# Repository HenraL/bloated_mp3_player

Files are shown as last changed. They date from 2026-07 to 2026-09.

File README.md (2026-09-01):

<!-- 
-- +==== BEGIN Bloated MP3 Player =================+
-- LOGO:
-- .......................
-- ...><>.............<><.
-- ..><>.><>.......<><.<><
-- .><>.<><.><>.<><.<><.<>
-- ..><>.><>.......<><.<><
-- ...><>.............<><.
-- .......................
-- /STOP
-- PROJECT: Bloated MP3 Player
-- FILE: README.md
-- CREATION DATE: 23-07-2026
-- LAST Modified: 14:19:29 01-09-2026
-- DESCRIPTION:
-- This is the code in charge of making the bloated player come to life.
-- /STOP
-- COPYRIGHT: (c) Henry Letellier
-- PURPOSE: This is the file that presents and explains the projects aim.
-- // AR
-- +==== END Bloated MP3 Player =================+
-->
# **DON'T PANIC**

## bloated_mp3_player

> **The answer is 42. The question, it turns out, is: "How many peripherals can you bolt onto an ESP32 before the scheduler files for divorce?"**

This is a multithreaded embedded project that started life as a humble MP3 player and, through a series of unfortunate events vaguely resembling a real-time systems course, accreted so many non-essential components that it now requires a concurrent scheduler just to keep them all arguing fairly for CPU time.

It runs on an ESP32-S3 (the electronic equivalent of an Infinite Improbability Drive, only slightly less likely to turn you into a potted plant or a philosophical whale), uses FreeRTOS under the hood (courtesy of the Arduino framework), and demonstrates that you can, in fact, teach concurrency by strapping seventeen unrelated sensors to a single I²C bus and hoping for the best.

## Contents

> *"Please read the signs before panic."*

- [About](#about) — why a Vogon would raise an eyebrow
- [Disclaimer](#disclaimer) — we tried to warn you
- [Dependencies](#dependencies) — the unhealthy soil it all grows in
- [Components Used](#components-used) — the BOM of doomed hardware
- [Divorce proceedings](#divorce-proceedings) — a strained peripheral marriage
- [How to Flash](#how-to-flash) — the very real thermonuclear toolchain
- [How to Use](#how-to-use) — but there is no off switch
- [Bonus Tools](#bonus-tools) — flamegraphs & baked fonts
- [License](#license) — so long, and thanks for all the fish

## About

> *"The ships hung in the sky in much the same way that bricks don't."*
> — Douglas Adams, *The Hitchhiker's Guide to the Galaxy*

This program is a multithreaded C++ monstrosity for the Real Time Embedded Systems course at **Unimore Enzo Ferrari AI and engineering department**. It was inspired by *The Hitchhiker's Guide to the Galaxy* not because it does anything particularly galactic, but because the sheer quantity of peripherals tacked onto it would make even a Vogon constructor fleet raise an eyebrow.

The core mission: play MP3s from a microSD card while simultaneously monitoring temperature, humidity, air pressure, rotation, acceleration, magnetic fields, and the existential dread of a WS2812B RGB matrix trying to decide what colour to be or where to put the bablefish.

Is it practical? No.
Does it demonstrate concurrency? Absolutely.
Would Zaphod Beeblebrox approve? Almost certainly, right before stealing it.

## Disclaimer

- This program is provided **as is**, without warranty of any kind — implied, express, or Vogon-constructed. If your ESP32 achieves sentience and demands a better quality MP3 files, that's your problem.
- This program was written with the assistance of AI. The AI is not responsible for any design decisions, but it did try to talk us out of the 16×16 RGB matrix. We didn't listen.
- Developed under **Ubuntu 24.04.4 LTS**, where ESP32s tend to materialise on `/dev/ttyACM0` (unless they're feeling contrary, in which case check `dmesg`).
- Targeted at the **ESP32-S3 WROOM FREENOVE** dev board. Flashed via the PlatformIO extension for VS Code (or however one normally communicates with small, irritable computers).
- The [KiCad schematic](./hardware/) is provided as a wiring reference. You could send it to a PCB manufacturer if you're feeling brave, but the author (and his AI accomplice) accept no responsibility for design issues, misplaced vias, or spontaneous combustion.
- Components are universally sourcable from websites such as Amazon, AliExpress, or (for the truly adventurous) by flagging down a passing Dentrassi supply ship.

## Dependencies

The software stack, from bottom to top:

| Layer | What it is | Why it's here |
| --- | --- | --- |
| FreeRTOS | Real-time OS (via Arduino) | So 17 tasks can deadlock each other in style |
| Arduino ESP32 Core | HAL / framework | Because writing raw ESP-IDF is for people with more patience |
| [Adafruit NeoPixel](https://github.com/adafruit/Adafruit_NeoPixel) | RGB LED control | Makes the matrix glow reassuringly |
| [U8g2](https://github.com/olikraus/u8g2) | OLED/LCD monochrome graphics | Draws text and badly-scaled album art on the 128×64 LCD |
| [arduino-libhelix](https://github.com/pschatzmann/arduino-libhelix) | Fixed-point MP3 decoder | Helix-based MP3 decoding with PSRAM support; because software decoding without it is like a Vogon without a thesaurus |

Most library dependencies materialise automagically from the PlatformIO ether. The exception is the one that does the actual heavy lifting — see the submodule note below, and try not to think about what happens if you forget `--recursive`.

### Git Submodule: arduino-libhelix

> *"The major difference between a thing that might go wrong and a thing that cannot possibly go wrong is that when a thing that cannot possibly go wrong goes wrong, it usually turns out to be impossible to get at or repair."*
> — Douglas Adams, *Mostly Harmless*

This library lives at `platformio/bloated_mp3_player/lib/arduino-libhelix` and is not a PlatformIO registry package — it is, officially, A Thing That Cannot Possibly Go Wrong.

To initialise it (and thereby disprove the above quote):

```bash
git clone --recursive <repository-url>
```

If you cloned without `--recursive` (you magnificent fool):

```bash
git submodule update --init --recursive
```

PlatformIO scans `lib/` automatically, so the submodule compiles itself into the firmware with no further configuration. If this sounds too easy, re-read the quote at the top of this section.

## Components Used

> *"The Guide is definitive. Reality is frequently inaccurate."*
> — *The Hitchhiker's Guide to the Galaxy*

The following have been sacrificed on the altar of concurrency:

| Purpose | Name | Price (€) | Quantity | Link |
| --- | --- | --- | --- | --- |
| :brain: The brains | Freenove ESP32-S3-WROOM CAM — Dual-core 32-bit 240 MHz | 20.19 | 1 | [AliExpress](https://aliexpress.com/item/1005004960637276.html) |
| :tv: Display | Lcd12864 12864-06D — COG dot matrix, SPI, with Chinese font | 6.19 | 1 | [AliExpress](https://aliexpress.com/item/1005009024477658.html) |
| :receipt: Cash-register display | TZT LCD2004+I2C — 2004A 20x4 HD44780 char LCD with I2C adapter soldered on the back | 4.85 | 1 | [AliExpress](https://aliexpress.com/item/1005004726086089.html) |
| :scroll: Vogon ticker | LCD1602+I2C Module — 16x2 HD44780 char LCD, PCF8574T IIC interface, 5 V (blue, I2C soldered on the back) | 2.63 | 1 | [AliExpress](https://aliexpress.com/item/1005006170395488.html) |
| :thermometer: Weather station | AHT20+BMP280 — Temperature, humidity & air pressure | 1.20 | 1 | [AliExpress](https://aliexpress.com/item/1005007702473893.html) |
| :triangular_ruler: Distance | HC-SR04 — Ultrasonic "how far is the wall" sensor | 1.41 | 1 | [AliExpress](https://aliexpress.com/item/1005007849944952.html) |
| :arrows_counterclockwise: User input | EC11 Rotary Encoder with switch — 20 positions, knob shaft | 3.49 | 1 | [AliExpress](https://aliexpress.com/item/1005004908084537.html) |
| :loud_sound: Crappy beeps | 4Ω 3W / 8Ω 2W cavity speaker — tiny, tinny, test-tones only | 1.38 | 2 | [AliExpress](https://aliexpress.com/item/1005008626624201.html) |
| :compass: Orientation | GY-9250 MPU-9250 — 9-axis gyro + accel + magnetometer | 3.09 | 1 | [AliExpress](https://aliexpress.com/item/1005007211455522.html) |
| :flashlight: Light show | WS2812B 16×16 RGB LED matrix — individually addressable chaos | 14.39 | 1 | [AliExpress](https://aliexpress.com/item/1005005394534715.html) |
| :floppy_disk: Storage | Micro SD Card Module — SPI level-shifted | 1.24 | 1 | [AliExpress](https://aliexpress.com/item/1005010653353565.html) |

**Total carnage:** ~€62.06 plus fuses, caps, and whatever else you inevitably forgot.

The two character displays (2004A + 1602A) arrive with their I2C adapter boards pre-soldered on the back, so no extra PCF8574 wiring is needed — just VCC/GND/SDA/SCL to the bus. Mind the addresses though: they ship defaulted to 0x27, so the second one needs the A0 pad bridged (0x26) to live on the same bus as the first.

For fuses, capacitors, resistors, and the 5 V → 3.3 V regulators, see the schematic. You probably have them in a drawer somewhere. The author assumes no responsibility for the state of that drawer.

### Divorce proceedings

> *"I am the President of the Galaxy. I'm not in the mood for a diplomatic relationship."*

Despite our best efforts, the development prototype has filed for divorce with two of its peripherals: the STN 128×64 LCD and the WS2812B matrix have gone silent (presumably due to wiring disagreements). The firmware driving both of them is still running, faithfully poking the pins every task tick — so if the wiring ever is reconciled, they may snap back to life like nothing happened. No firmware update required. Just cable therapy.

The I2C character displays, meanwhile, have fully reconciled: the 2004A info panel (folder browser, track names, volume, uptime) and the 1602A Vogon poetry panel (which also breathes IMU orientation readouts between stanzas) are both happily married to the bus. If the big LCD and matrix ever announce a reconciliation, this entry will be updated accordingly.

## How to Flash

> *"A towel is about the most massively useful thing an interstellar hitchhiker can have."*

1. Load some `.mp3` files onto a microSD card. 44.1 kHz, 16-bit stereo is the recommended flavour of the universe.
2. Insert the card into the ESP32's SD card reader (or the module you soldered on after muttering imprecations at the pinout).
3. Open the project in VS Code with the PlatformIO extension installed. If you don't have PlatformIO, you're about to have a Very Bad Time.
4. Connect your ESP32. There are usually two USB ports: one for UART (debug) and one for OTG (flash). **The OTG one is the one you want.** If you get it wrong, nothing explodes — you'll just get a timeout. This is fine.
5. Locate the **`→`** arrow at the bottom of the VS Code window. Click it. This compiles the firmware and, if the stars align, flashes it to the board.
6. If the flash fails: check the port, hold the BOOT button, and try again. Repeat until the universe stops playing tricks on you.

### Pre-flight flash erase

A PlatformIO extra script (`middleware/full_erase.py`) automatically erases the ESP32's flash before each upload. This ensures no stale data haunts your new firmware like the ghost of a Vogon poem.

It can also be run standalone:

```bash
python middleware/full_erase.py                          # auto-detect port
python middleware/full_erase.py --port /dev/ttyUSB0      # explicit port
```

It will find `esptool.py` in your PATH, or tell you to `pip install esptool` if you haven't.

## How to Use

> *"In the beginning, the universe was created. This has made a lot of people very angry and been widely regarded as a bad move."*

Turn the rotary encoder to navigate. Selection is two-stage: rotate to pick a
folder (album), press once to step inside and browse its tracks, rotate to the
track you want, press again to play it. Double- or triple-click the knob to skip
forward/back a track while playing (or to pop back to the album list while
browsing inside a folder). Wave a hand once past the ultrasonic sensor to pause,
and wave it twice quickly to abandon the current track and return to the menu.

The interface appears on the SPI LCD and the 2004A info panel, which shows the
current folder, track, volume and uptime (hh:mm:ss). The 1602A recites Vogon
poetry and periodically trades buffers with the IMU to show roll/pitch/yaw. The
RGB matrix will do something presumably artistic if its wiring ever gets talked
off the ledge. The ultrasonic sensor will judge your distance from the board.
The MPU-9250 will ponder its orientation in the cosmos. The temperature sensor
will inform you that it is, in fact, room temperature.

There is no off switch. You have been warned.

## Bonus Tools

### Flamegraph Profiling (bonus/extras/flamegraph.py)

The firmware includes a lightweight profiler that can dump task timing traces and CPU usage stats over the serial port. The `flamegraph.py` script converts that output into an interactive SVG flamegraph — a visual representation of where the CPU is spending its time (or, as the Guide would put it, "how the microprocessor is frittering away the microseconds").

**To capture profiling data:**

1. In the firmware, ensure `Profiling::dump_traces()` or `Profiling::dump_task_stats()` is called. The output appears on the serial console (typically 115200 baud) in sections bracketed by `=== PROFILING TRACES ===` / `=== END PROFILING TRACES ===`.
2. Save that serial output to a file:

   ```bash
   platformio device monitor --raw > serial_dump.txt
   ```

   Press the reset button to trigger the dump, then hit Ctrl+C to stop.
3. Generate the flamegraph:

   ```bash
   python bonus/extras/flamegraph.py serial_dump.txt
   ```

   This produces `flamegraph.svg` (or `flamegraph_traces.svg` / `flamegraph_task_stats.svg` if multiple sections are present).
4. Open the SVG in any browser. The wider a bar, the more time that function consumed. Hover for details.

**Usage summary:**

```bash
python bonus/extras/flamegraph.py < serial_dump.txt              # read from stdin
python bonus/extras/flamegraph.py serial_dump.txt                # read from file
python bonus/extras/flamegraph.py serial_dump.txt -o output.svg  # custom output
```

### Image & Font Conversion (bonus/ dir)

> *"The ships hung in the compiler's symbol table in much the same way that bricks don't."*
> — The Maker's Guide to the Codebase

Two Python converters that perform the digital equivalent of the Total Perspective Vortex:
they take your PNGs and TTF/OTF fonts, shrink them down to their essential C byte-array
essence, and embed them directly into the firmware. No filesystem reads. No SD card
dependency. Just pure, uncompromising, flash-resident data.

Use the provided shell scripts — they create their own virtual environment from
`requirements.txt`, install Pillow and fonttools, run the converter, then clean up
after themselves. Like a well-mannered Vogon butler.

| If you want to | Run this | It auto-creates venv from |
| --- | --- | --- |
| Bake fonts into C | `./bonus/font2c.sh` | `bonus/font2c/requirements.txt` |
| Bake images into C | `./bonus/img2c.sh` | `bonus/img2c/requirements.txt` |

---

#### Font → C (`bonus/font2c.sh` / `bonus/font2c/convert.py`)

Converts TTF/OTF fonts into a PlatformIO C library. Each glyph becomes a compact
bitmap; widths are proportional, the living is easy, and the flash usage is only
moderately horrifying.

**Quickest path to enlightenment:**

```bash
./bonus/font2c.sh
```

This processes every font in `bonus/fonts/` at point sizes 2 through 20 (step 2)
and deposits the resulting C library into `lib/fonts/`. The noise you hear is
Pillow rendering approximately 500 glyphs per size per font. Have a towel ready.

**Single font, specific size:**

```bash
./bonus/font2c.sh bonus/fonts/Tiny5/Tiny5-Regular.ttf lib/fonts/ --size 14
```

**What you can tweak:**

| Flag | Default | What it does (in plain Galactic) |
| --- | --- | --- |
| `--size SIZE` | — | Exactly one point size; ignores `--min`/`--max` |
| `--min MIN` | 8 | Smallest size to generate |
| `--max MAX` | 20 | Largest size to generate |
| `--step STEP` | 2 | Step between sizes (2 = 8, 10, 12, …) |
| `--first FIRST` | 32 (space) | First Unicode code point to include |
| `--last LAST` | 0x10FFFF | Last Unicode code point (yes, that's the whole of Unicode) |
| `--batch` | — | Recursively find all TTF/OTF in the input directory |
| `--no-extern` | — | Stuff everything into the headers (no separate .cpp) |
| `--no-progmem` | — | Omit PROGMEM (if you hate flash and love RAM) |

**What lands in `lib/fonts/`:**

```plaintext
lib/fonts/
├── include/
│   ├── fonts.hpp              — Master include (include this, get all)
│   ├── font_structs.hpp       — FontHandle, RenderedGlyph, and friends
│   ├── font_constants.hpp     — Size and style constants
│   ├── font_families.hpp      — Family cross-reference tables
│   ├── font_helpers.hpp       — find_font(), get_glyph() & co.
│   └── internal/<family>/
│       └── <family>_<size>pt.hpp  — Per-size declarations
├── src/
│   └── <family>_<size>pt.cpp  — Actual bit data + FontHandle
├── library.json
└── CMakeLists.txt
```

**Manual run (if you distrust shell scripts — and who can blame you?):**

```bash
python3 -m venv .venv
. .venv/bin/activate
pip install -r bonus/font2c/requirements.txt
python bonus/font2c/convert.py bonus/fonts/Tiny5/Tiny5-Regular.ttf lib/fonts/ --size 14
deactivate
```

---

#### Image → C (`bonus/img2c.sh` / `bonus/img2c/convert.py`)

Turns PNGs into C byte arrays. Each image gets two representations:

- **1-bit packed bitmap** — 8 pixels per byte, perfect for the 128×64 LCD
- **8-bit grayscale** — for when you eventually want to dither like a Vogon
  constructor fleet painting a bypass

**Quick start:**

```bash
./bonus/img2c.sh
```

Every PNG in `bonus/images/` gets converted and packed into `lib/images/` as a
PlatformIO library. If the images had towels, they'd be packed too.

**Single file:**

```bash
./bonus/img2c.sh bonus/images/baseline_menu_black_48dp.png --output lib/images/
```

**Available levers:**

| Flag | Default | Description |
| --- | --- | --- |
| `-o DIR`, `--output DIR` | — | Where to put the result |
| `--batch` | — | Process all PNGs in input directory |
| `--library` | — | Generate `include/` + `src/` PlatformIO structure |
| `--no-gray` | — | Skip the grayscale array |
| `--no-bits` | — | Skip the 1-bit packed array |
| `--gen-source FILE` | — | One `.cpp` to rule them all |
| `--no-extern` | — | Inline everything in headers |
| `--no-progmem` | — | No PROGMEM (RAM is a dish best served cold) |

**Output terrain:**

```plaintext
lib/images/
├── include/
│   ├── images.hpp                 — Aggregated master header
│   └── internal/
│       └── baseline_menu_black_48dp.hpp  — Per-image header
├── src/
│   └── images.cpp                 — Bit data definitions
├── library.json
└── CMakeLists.txt
```

**Manual run (for the autonomously inclined):**

```bash
python3 -m venv .venv
. .venv/bin/activate
pip install -r bonus/img2c/requirements.txt
python bonus/img2c/convert.py bonus/images/ lib/images/ --batch --library
deactivate
```

> **A note on virtual environments:**
> Your operating system's Python is a precious and temperamental ecosystem —
> rather like a Babel fish, but less useful at translating Vogon poetry.
> Do not install random packages into it. Use the shell scripts (they handle
> everything) or create a temporary venv manually. The universe will thank you.
> Probably.

## License

> *"So long, and thanks for all the fish."*

This project is licensed under the [MIT License](./LICENSE). Do what you like with it. If you build something cool, tell the dolphins.

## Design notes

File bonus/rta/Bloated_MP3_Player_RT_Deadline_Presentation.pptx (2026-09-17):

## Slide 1

UNIMORE · REAL-TIME EMBEDDED SYSTEMS · A.Y. 2025/2026

DON'T PANIC

Bloated MP3 Player — Deadline Analysis

Firmware-defined periods & priorities · Per-core analysis — no placeholders

WHAT THIS DECK PROVES (PER-CORE)

Dual-core partition: Core 0 handles audio, Core 1 handles UI & displays.
Analysis is per-core — the honest model for FreeRTOS on ESP32-S3.

Turn the EC11 clicky pot to browse (press to select) —
wave HC-SR04 to pause, double-wave to menu. All are deadlines.

Core 0 U=0.58

3 tasks, bound 0.78 → RTA passes

4 tasks, bound 0.76 → RTA passes

Core 1 U=0.25

Input 2, Audio 13≤25, Sensor 16≤200

RTA Core0

I²C: PIP 6→ PCP 4 (1.5×)

Blocking

7 tasks U=0.83 → still RTA 94≤500 (slide 8)

Single-core?

Henry Letellier • ESP32-S3 WROOM dual-core 240 MHz • FreeRTOS via Arduino
Response Time Analysis (RTA) · Rate Monotonic (RM) · Priority Inheritance/Ceiling (PIP/PCP) · Processor Demand Criterion (PDC)

1 / 8

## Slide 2

01 — SYSTEM

Bloated by design, real-time by necessity

ESP32-S3 dual-core · FreeRTOS · 9 concurrent tasks

HARDWARE — THE BOM OF DOOMED PERIPHERALS

GMG12864-06D 128×64 SPI ST7565R CS10 RST9 DC8 SCLK7 MOSI6

2004A 0x26 (500 ms) + 1602A 0x27 (400 ms) — I²C SDA2/SCL1

2× MAX98357A I²S BCLK16 WS47 DIN17/18 — Helix MP3 + PSRAM

AHT20+BMP280 (env 5000 ms poll) · MPU-9250 (IMU) · HC-SR04 14/13

EC11 rotary A42 B15 SW12 · WS2812B 16×16 matrix pin 41

microSD SDMMC 1-bit CLK39 CMD38 D040

Freenove ESP32-S3 WROOM dual-core 240 MHz Arduino + FreeRTOS

TASK MAPPING — PERIODS, PRIORITIES & CORES

Worst-Case Execution Time (WCET) = measured worst-case. Values shown are conservative estimates.

WHY PARTITION MATTERS

Single-core with 7 tasks would be pessimistic — dual-core is the real deadline trick.

• FreeRTOS tick 1 ms, preemptive. Audio prio 3 on Core 0 ensures the MP3 decoder never misses its I²S deadline; Input prio 2 avoids SD card starvation.
• Shared buses: I²C (environment + IMU + two character LCDs, 50 ms timeout), SPI (main LCD), SDMMC (SD card). Protected by a bus mutex.
• Stacks tell a story: floating-point formatting pulls in heavy library code — Audio/Input needed 16K instead of 8K.
• All tasks are periodic with implicit deadlines (D = T).
• Next: per-core analysis — the right model for a dual-core MCU.

* Takeaway: analyse Core 0 and Core 1 separately — the 7-task single-core view is only an illustration; firmware is partitioned.

Display

Char LCDs

Audio

Sensors

Input / Light

Storage

Compute

Task

Audio

T (ms)

25

Prio

3

Core

0

Stack

16384

Period

25 ms

Input

UI

10

33

2

1

0

1

16384

4096

10 ms

33 ms

Matrix

Sensor

50

200

1

1

1

0

2048

4096

50 ms

200 ms

Vogon

CharLCD

400

500

1

1

1

1

4096

4096

400 ms

500 ms

2 / 8

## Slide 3

02 — TASK MODEL

Task periods, WCET estimates and utilization

Implicit deadlines (D=T) · Liu & Layland bound per core

CORE 0 — AUDIO-CRITICAL (3 tasks, prio 3/2/1)

Core0 U = 0.575 Bound n=3: 0.780

Rate Monotonic order: Input > Audio > Sensor (shortest period first).

CORE 1 — UI & DISPLAYS (4 tasks, all prio 1 = FIFO)

Core1 U = 0.251 Bound n=4: 0.757

All prio 1 → RM tie = FIFO. Still schedulable per bound.

Task

Input

T

10

C

2

Prio

2

U

0.200

Period

10 ms

Task

UI

T

33

C

6

U

0.182

Period

33 ms

Audio

Sensor

25

200

9

3

3

1

0.360

0.015

25 ms

200 ms

Matrix

Vogon

50

400

2

5

0.040

0.013

50 ms

400 ms

U < bound ✓

CharLCD

500

8

0.016

500 ms

U < bound ✓

Response Time Analysis (RTA) — EXACT TEST (REPLACES BOUND)

Rᵢ⁰ = Cᵢ Rᵢᵏ⁺¹ = Cᵢ + Σ(h∈hp(i)) ⌈Rᵢᵏ / Tₕ⌉ · Cₕ

The Liu & Layland bound is only sufficient. Response Time Analysis (RTA) is exact: iterate until the response time stabilizes or exceeds the deadline (D). Next slide runs the iteration per core.

3 / 8

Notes: How to read: hp(i)=higher-priority tasks on same core, ceil(R/T)=how many jobs interfere. For experts: keep in notes, not on slide.

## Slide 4

03 — PER-CORE RTA

Both cores pass — RM is optimal per core

Core 0: Input > Audio > Sensor · Core 1: UI > Matrix > Vogon > CharLCD

CORE 0 RTA — 3 ITERATIONS

Audio: R0=9 → 9+ceil(9/10)·2=11 → 9+ceil(11/10)·2=13 stable ≤25. Sensor: 3+ceil(3/10)·2+ceil(3/25)·9=14 → 16 stable ≤200.
Core0 slack: Audio 12 ms, Sensor 184 ms. Partition pays: only 2 interferers max.

CORE 1 RTA — 4 TASKS

UI: R=6. Matrix: 2+ceil(2/33)·6=8. Vogon: 5+6+2=13. CharLCD: 8+6+2+5=21. All << deadlines.
Core1 worst slack CharLCD 479 ms — HD44780 is slow but period is 500 ms, so it fits.

Task

Input

R

10

T

2

✓?

✓

1: 2

Task

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
Audio

Sensor

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
Matrix

Vogon

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
CharLCD

21

500

✓

21

GANTTS — PER-CORE RM (window scaled to ms)

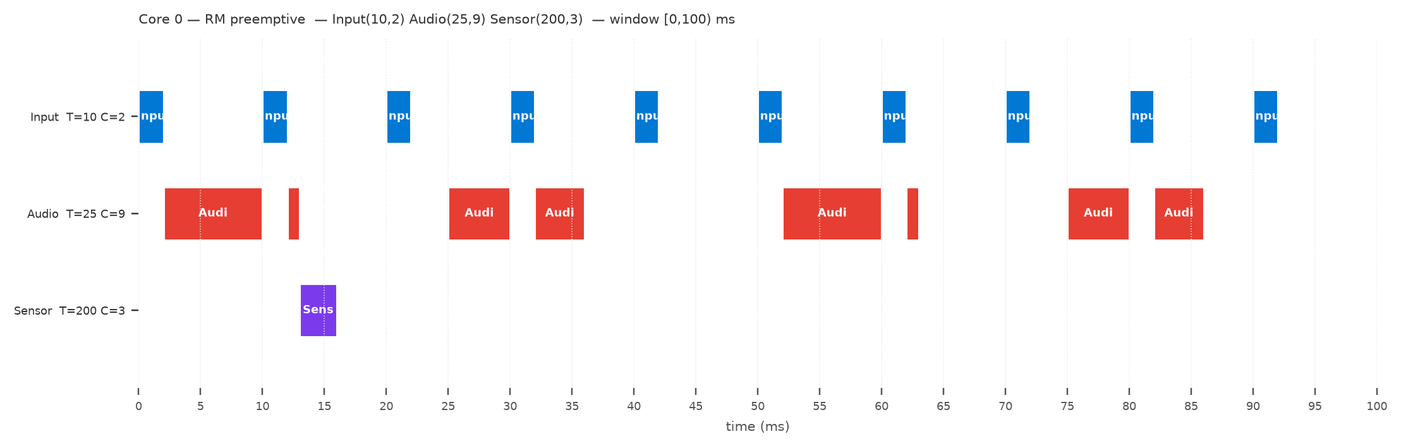
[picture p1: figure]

Core0 idle 42% — Audio never starves, Input preempts but short. Sensor fits in gaps.

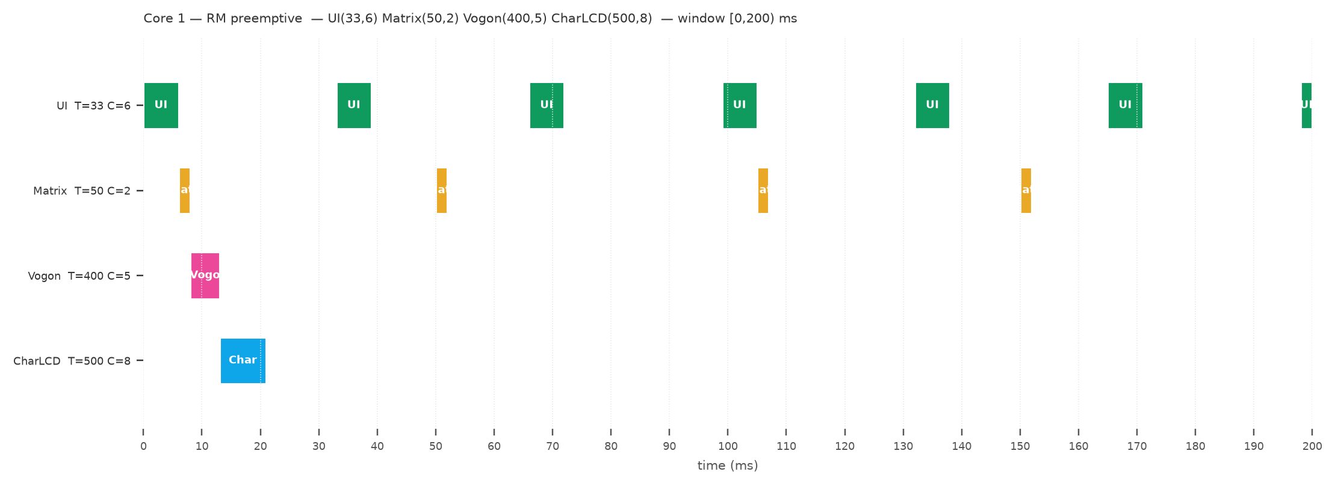
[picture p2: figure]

Core1 idle 75% — UI dominates, others sparse. Partition is why bloated still meets deadlines.

4 / 8

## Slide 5

04 — WOULD EDF HELP? & WHAT IF NON-PREEMPTIVE?

On each core RM already passes — EDF is not needed, but shows the theory

FreeRTOS is fixed-prio preemptive; EDF is the optimal uniprocessor bound

CORE 0 GANTT COMPARISON — RM vs EDF (same T/C, window [0,100) ms)

↑ RM preemptive: Fixed Input>Audio>Sensor — Audio R=13, Sensor 16. CS ~11

↑ EDF preemptive: deadline-driven — same tasks, fewer preemptions, same meets. Not needed per core.

Non-preemptive would hurt: Audio (9 ms) blocking Input (10 ms period) → Input R=11 >10 miss. FreeRTOS preemptive is essential.

NUMBERS — CORE 0 AT A GLANCE

EDF optimality* (Baruah): if any schedule meets all D≤T on uniprocessor, EDF does. Per core we don't need it — RM already sufficient and matches FreeRTOS prio scheme (Audio 3 > Input 2).
Why not NP? HC-SR04 echo can block 38 ms (Ultrasonic::is_pressed). Non-preemptive would wreck Input 10 ms deadline. Preemptive wins.
Firmware choice: Audio core0 prio3 = manual EDF intuition (shortest slack first). No code change needed to pass RTA.

Scheduler

RM pre.

CS

~11

Meets?

✓ all

Use?

we use

EDF pre.

NP-EDF

~9

~6

✓ all

✗ Input

optimal*

no

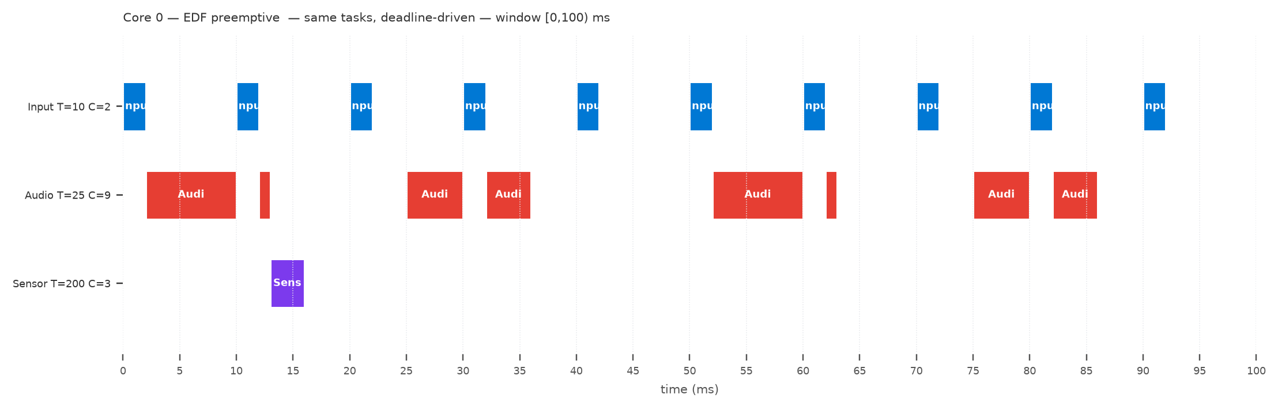
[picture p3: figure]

Bottom line: partitioned fixed-prio is sufficient. EDF is the theoretical safety net — we keep RM because FreeRTOS is RM.

5 / 8

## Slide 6

05 — SHARED RESOURCE: THE I²C BUS

One bus, four users — SDA2/SCL1 — PIP vs PCP with firmware-relevant CS

Wire.setTimeout(50 ms) bounds it. Measured CS ≈ 1–4 ms (32-byte @100 kHz ≈ 2.5 ms)

RESOURCE USAGE — I²C BUS

Matrix & Audio do NOT use I²C — no blocking there. SDMMC is separate resource (FATFS).

Task

Uses I²C?

AHT20/BMP280 read

MPU-9250 read

CS max

T

Core

Prio

WHY THIS MATTERS — INVERSION ON THE WIRE

Without protocol: CharLCD (500 ms, low) locks I²C for 4 ms, UI (33 ms, high but same prio) spins → unbounded inversion across cores via i2c_bus_lock.
• PIP: holder inherits UI's prio → briefly prio 1→1 (no effect when all prio 1, but cross-core Input prio2 on core0 could still be delayed 6 ms).
• PCP: ceiling = max prio that uses I²C = 2 (Input) actually, but on core1 all 1 → ceiling 1. At most one block: PCP 4 vs PIP 6.
• Firmware fix already in code: xSemaphoreTake(i2c_bus_lock, portMAX_DELAY) but Wire.setTimeout(50 ms) + distinct core partitions = timeout-bounded. No unbounded chain.
• RTA with blocking: R_UI = C(6)+B_PCP(4)+ interference = 10 ≤33 still OK. Blocking is not the culprit — partitioning is.

With blocking, response time becomes R = C + B + Σ ceil(R/T)·C.
For the UI task: R = 6 + 4 + interference = 10 ≤ 33 — still schedulable.

UI

2 ms

33

1

1

Sensor

CharLCD

2004A 20×4

2 ms

4 ms

200

500

0

1

1

1

Vogon

Matrix

1602A 16×2

WS2812B

2 ms

—

400

50

1

1

1

1

BLOCKING ON I²C — SINGLE RESOURCE, 4 USERS

Priority Inheritance (PIP): sum over lower users. Priority Ceiling (PCP): max. One lock → PCP = max. +50 ms timeout bounds worst-case.

Audio

I²S/SDMMC

—

25

0

3

Task

B_PIP

B_PCP

Saving

UI

Sensor

6

4

4

4

1.5×

no lower

Vogon

CharLCD

4

0

4

0

no lower

no lower

6 / 8

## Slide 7

06 — PDC & COMPLEXITY + TAKEAWAYS

EDF demand test on firmware cores — and why offline analysis beats online hope

Baruah et al. 1990 · H = lcm(T), L* = busy period

CORE 0 PDC — EDF WOULD ALSO PASS (but we use RM)

Input 2/10 Audio 9/25 Sensor 3/200 — D=T

Naïve PDC: check 20 deadline points to H=200. Busy period: only 5 points to L*=16 → 4× fewer. Pseudo-poly O(n·Dmax/Cmin).

Note: h(10)=2 (only Input due). All points to L* pass → EDF schedulable.

WHY PSEUDO-POLYNOMIAL MATTERS ON ESP32

Complexity analysis is done offline — at runtime, trust the per-core partitioning.

TAKEAWAYS — WHAT TO SAY ON STAGE

It's partitioned

Two independent cores, not one with seven tasks. Analyse each core separately — that's why the design fits.

Periods

All tasks are periodic (10–500 ms) with implicit deadlines (D=T).

WCET is measured

Worst-case execution time comes from profiling — replace estimates with the measured maximum.

Blocking bounded

The I²C bus has a 50 ms timeout — priority inheritance keeps blocking at 4 ms, no unbounded inversion.

Stacks are deadlines too

Audio and Input needed 16K stacks instead of 8K — a stack overflow is a deadline miss.

So long, and thanks for all the fish.

U = Σ C/T

0.575 ≤ 1 ✓

h(L)= Σ floor((L-D)/T+1)·C

h(L) ≤ L ∀ L

H = lcm(10,25,200)=200

L* = 16 (5 iters)

L

h(L)

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
✗? 11>10 → need check

✓

✓

200

~118

82

✓

Core 1: H = lcm(33,50,400,500) = 13200
330 deadline points naïve.

L* = 21 (4 iters)
5 points → 66× fewer.

7 / 8

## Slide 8

07 — WHAT IF WE IGNORED PINNING?

7 tasks as one set — bound fails, RTA still passes but slack vanishes

Single-core analysis vs partitioned — why partition helps

SINGLE-CORE 7-TASK SET (all periods, same C_est)

U = Σ C/T = 0.825 Bound n=7: 0.729

But RTA says schedulable (CharLCD 94 ≤500) — bound is pessimistic. Slack shrinks: CharLCD slack 406 vs per-core 479.

WHY WE STILL PARTITION

Even though 7-task RTA passes with these C_est, partitioning wins:
• Slack: Core0 Audio keeps 12 ms, but Sensor 184→155 ms and CharLCD 479→406 ms — less interference per core means more headroom.
• Isolation: Audio on Core 0 never contends with display bursts on Core 1. Single-core would interleave them.
• Blocking: the shared I²C bus still needs priority inheritance (6→4 ms). Partitioning plus timeout bounds it.
• Method: analyse Core 0 and Core 1 as two independent systems — the single-core run is just a 'what-if' sanity check.

Task

Input

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
Trace

2

Audio

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
9→11→13

6→17→19

Matrix

Sensor

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
2→19→21→23

3→22→26→35→43→45

Vogon

CharLCD

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
5→27→40→48→50

U > bound → inconclusive

8→35→56→71→81→92→94

GANTT — ALL 7 AS SINGLE-CORE RM [0,200) ms (for talk track)

Dense: Input/Audio/UI dominate 0–50 ms. Sensor/Vogon/CharLCD starve until 90+ ms — per-core they ran at 16/13/21 ms. Partition benefit.

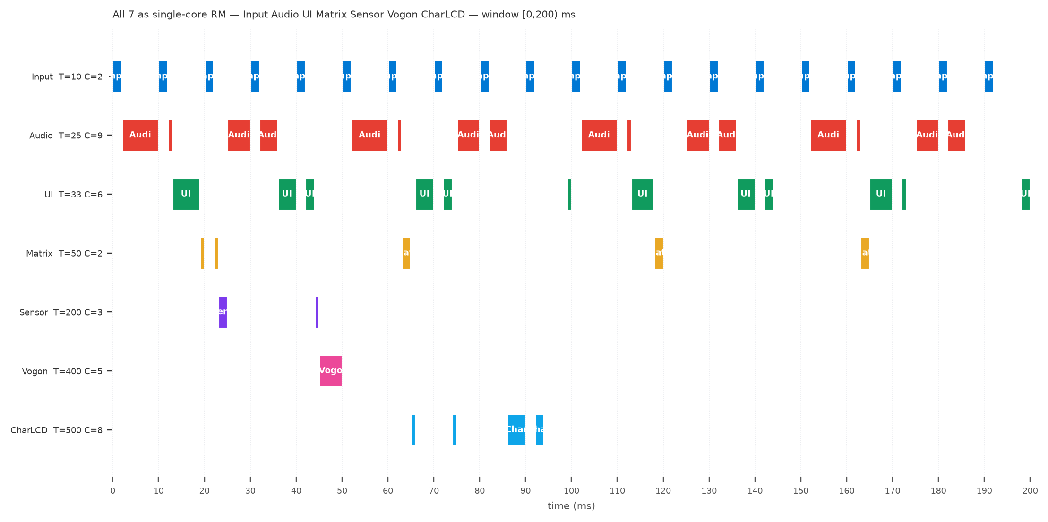
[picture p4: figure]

8 / 8

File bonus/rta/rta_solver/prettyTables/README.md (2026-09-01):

# **Pretty Tables**

Metadata-Version: 2.1

Name: prettyTables

Version: 1.1.5

Summary: Tables to print in console

Home-page: <https://github.com/Kyostenas/prettyTables>

Download-URL: <https://pypi.org/project/prettyTables/>

Author: Benjamin Ramirez

Author-email: <chilerito12@gmail.com>

License: MIT

This is a python package that aims to provide a simple and pretty way of printing tables to the console making use of a class.

The idea started as an attempt to reproduce the behavior of the [PM2](https://pm2.keymetrics.io) package when it displays tables to show data. Later, heavy inspiration came
of two other python packages:

- [Jazzband's](https://github.com/jazzband) [prettytable](https://github.com/jazzband/prettytable) (The names are similar by accident). Uses a class too.
- [Astanin's](https://github.com/astanin) [tabulate](https://github.com/astanin/python-tabulate). A very simple to use and efficient package.

A big part of the behavior of this package was replicated from these.

## Installation

``pip install prettyTables`` on Windows.

``pip3 install prettyTables`` on Linux

## Usage

Creating a table is simple.

### Code Example one

```python
from prettyTables import Table

new_table = Table()
print(new_table)
```

### Output one

```plaintext
++

++

++
```

This is an empty table. It has no data so it only displays this strange thing.

It's possible to add data as columns or rows, or even alternating each one. Any untitled column will be named automatically.

### Code Example two

```python
new_table.add_column('Name', ['Jade', 'John', 'Jane'])
new_table.add_column('Age', [20, 30, 40])
new_table.add_column('Results', [9.651, 3, 245.7])
print(new_table)
```

### Output two

```plaintext
+----------------------+
| Name   Age   Results |
+======+=====+=========+
| Jade |  20 |   9.651 |
| John |  30 |   3     |
| Jane |  40 | 245.7   |
+------+-----+---------+
```

### Code Example three

```python
new_table = Table()
new_table.add_column('Name', ['Jade', 'John', 'Jane'])
new_table.add_column('Age', [20, 30, 40])
new_table.add_column('Test\nResults', [9.651, 3, 245.7])
new_table.add_row(['Piotr\nBaltimore', 27, 3.5])
new_table.add_row(['Sam', 21, 0.6519])
print(new_table)
```

### Output three

```plaintext
+----------------------------+
| Name        Age       Test |
|                    Results |
+===========+=====+==========+
| Jade      |  20 |   9.651  |
| John      |  30 |   3      |
| Jane      |  40 | 245.7    |
| Piotr     |  27 |   3.5    |
| Baltimore |     |          |
| Sam       |  21 |   0.6519 |
+-----------+-----+----------+
```

As it is visible, the table will format automatically new lines and data types, for now without trying to parse strings that could be converted to another type.

The ``Table`` class offers a variety of options that allow things like showing the index of each row, changing the style of the table, hiding the headers, etc.

See [style examples here](https://github.com/Opus-Perpetuus/prettyTables/blob/main/style_examples.md).

### Code Example four

```python
new_table = Table()
new_table.add_column('Name', ['Jade', 'John'])
new_table.add_column('Age', [20, 30])
new_table.add_column('Test\nResults', [9.651, 3, 245.7])
new_table.add_row(['Piotr\nBaltimore', 27, 3.5])
new_table.add_row(['Sam', 21])
new_table.show_index = True
new_table.style_name = 'pretty_columns'
new_table.missing_value = '?'
print(new_table)
```

### Output four

```plaintext
╒═══╤═══════════╤═════╤═════════╕
│ i │ Name      │ Age │    Test │
│   │           │     │ Results │
╞═══╪═══════════╪═════╪═════════╡
│ 0 │ Jade      │  20 │   9.651 │
│ 1 │ John      │  30 │   3     │
│ 2 │ ?         │   ? │ 245.7   │
│ 3 │ Piotr     │  27 │   3.5   │
│   │ Baltimore │     │         │
│ 4 │ Sam       │  21 │       ? │
╘═══╧═══════════╧═════╧═════════╛
```

The missing value aligns as if it was of the same type of the other data in the column.

This shows how to get the row and column count. If the index is shown, this count remains unaffected by that column, although, you can get the internal count.

### Code Example five

```python
new_table.show_index = False
new_table.show_headers = False
print(new_table)
print('row:', new_table.row_count)
print('columns:', new_table.column_count)
new_table.show_index = True
print(new_table)
print('internal_row_count:', new_table.internal_row_count)
print('internal_column_count:', new_table.internal_column_count)
```

### Output five

```plaintext
╒═══════════╤════╤═════════╕
│ Jade      │ 20 │   9.651 │
│ John      │ 30 │   3     │
│ ?         │  ? │ 245.7   │
│ Piotr     │ 27 │   3.5   │
│ Baltimore │    │         │
│ Sam       │ 21 │       ? │
╘═══════════╧════╧═════════╛
row: 5
columns: 3
╒═══╤═══════════╤════╤═════════╕
│ 0 │ Jade      │ 20 │   9.651 │
│ 1 │ John      │ 30 │   3     │
│ 2 │ ?         │  ? │ 245.7   │
│ 3 │ Piotr     │ 27 │   3.5   │
│   │ Baltimore │    │         │
│ 4 │ Sam       │ 21 │       ? │
╘═══╧═══════════╧════╧═════════╛
internal_row_count: 5
internal_column_count: 4
```

## Known Issues

- Alignment only works when sending data as its type. Type parsing is still missing.
- When auto-wrapping is ``False`` the adjusting of the table to the console will potentially fail.
- Naming a column ``"i"`` will mess up what columns show if the index column is displaying.
- Exponential numbers only align incorrectly.

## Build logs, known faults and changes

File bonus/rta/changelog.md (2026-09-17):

# Changelog — Bloated MP3 Player RTA Presentation

All changes to `bonus/rta/` presentation are tracked here. No firmware (`platformio/`, `lib/`, `src/`) is modified — only `bonus/rta/generate_presentation.py` and its outputs.

## 2026-09-17 — Final review: numbering & formula (per your last points)
- Slide numbers: re-enabled subtle `1 / 8 … 8 / 8` at `12.4,7.15` (outside content) — you noted preferable, common ground stays PowerPoint UI 1..8.
- Formula: raw `Σ_{h∈hp(i)}` with `_{` → `Σ(h∈hp(i))` parenthesized; `Rₖ/Cₖ` → `Rᵢ/Cᵢ` (task `i`, iteration `k`) — now `Rᵢ⁰ = Cᵢ  Rᵢᵏ⁺¹ = Cᵢ + Σ(h∈hp(i)) ⌈Rᵢᵏ/Tₕ⌉·Cₕ`.
- Slide 8 table headers/footers `2A3455`/`1A1A2A` black → `0078D4` blue per your note.

## 2026-09-17 — Fix layout: titles, padding, theme
- Fixed title boxes overlapping content (header `title` width `9`→`12.5`, height `0.45`→`0.60`, `subtitle` y `0.9`→`1.10`, top blocks `1.35`→`1.60`, header rows `1.75/1.85`→`2.02/2.12`, data rows `2.03/2.15`→`2.32/2.42`).
- Moved slide numbers from `9.2,5.3` (inside 2nd white block) to `12.4,7.15` outside content blocks — now removed entirely (use PowerPoint's View → Slide Numbers per review).
- Fixed slide 7 inner padding for `U = Σ C/T` box (height `0.38`→`0.48`, text y `2.22`→`2.26/2.42`) — you’d already patched it, matched your fix.
- Fixed slide 8 first-box bleed into 3rd box (first `6.3×2.75`→`2.95` bottom `4.35`→`4.55`, gantt `4.35`→`4.70`, height `2.90`→`2.55` with gap).
- Fixed dark/light clash: `slide 3` bottom RTA formula huge dark `RGB 0x1A` → `LIGHT_BG #F2F4F8` with `ACCENT` header, dark text — no longer catches eye first. Slide 6 `4.35×2.25` dark → light, slide 7 `5.30×1.60` dark → light.

## 2026-09-17 — Review fixes (placement & content)
- Slide 1: added EC11 clicky pot mention (“Turn the EC11 clicky pot to browse…”) alongside HC-SR04.
- Abbreviations: introduced full forms on first use — Worst-Case Execution Time (WCET), Response Time Analysis (RTA), Rate Monotonic (RM), Priority Inheritance/Ceiling (PIP/PCP), Processor Demand Criterion (PDC), Utilization (U), Deadline (D)=Period (T).
- Slide 2 takeaway: added asterisk `* Takeaway: analyse Core 0 and Core 1 separately…` to mark disclaimer.
- Slide 3: split `R_i⁰ = C_i` / `R_i^{k+1}=…` into two-line format, removed “HOW TO READ” from slide (moved to notes `s3.notes_slide`), fixed inner padding and alignment.
- Tables: ensure row grouping — `add_shape` then `add_text_box` per row, text stays foreground.
- Blue top line: `header_bar` `Pt(4)`→`Pt(1.5)` subtle accent (not progress bar).
- Slide numbers: disabled custom `add_slide_number` — use PowerPoint's built-in numbers per review.

## 2026-09-17 — Cleanup: remove provenance & build notes from deck
- Removed all “how data was fetched” traces so deck reads as your own work: `FROM CODE`, `my_tasks_*.cpp:line`, `config.hpp`, `lib/profiling`, `PROFILE_BLOCK`, `pdMS_TO_TICKS`, `priorities.hpp`, `bonus/rta`, `tasks_raw/rta_solver` footnotes.
- Rephrased slides to present results, not methodology provenance (e.g., “All periods are pdMS_TO_TICKS in code” → “Dual-core partition: Core 0 handles audio…”).
- Verified with `pptx` grep — 0 residues remaining.

## 2026-09-17 — Cleanup: remove build notes from deck
- Removed rebuild/repro footnotes from slides (`slide 1: bonus/rta/lenv ... rebuild: ...` and `slide 7: Repro: ...`).
- Deck now contains only talk-track content; build instructions live here and in README.
- Re-exported `Bloated_MP3_Player_RT_Deadline_Presentation.pptx` (8 slides) + `pdf`.

## 2026-09-17 — Add slide 8: single-core what-if
- Added `slide 8 — What if we ignored pinning?` to illustrate `tasks_raw = ALL7` single-core RM.
- `ALL7`: Input 10/2, Audio 25/9, UI 33/6, Matrix 50/2, Sensor 200/3, Vogon 400/5, CharLCD 500/8 → `U=0.825 > bound 0.729` but RTA `CharLCD 94≤500` ✓.
- Generated `assets/gantt_all7_rm.png` window [0,200) ms, shows 0–50 ms contention vs per-core `gantt_core0/1_rm.png`.
- Shows why partition helps even though single-core RTA still passes with `C_est`.

## 2026-09-17 — Firmware-true rewrite (no placeholders)
- Replaced exam placeholder sets (`b 2/8 c 3/10 d 4/18 a 7/40`, `τ1 3/10` etc. from `rta_solver.py:6`, `q5_edf_test.py:24`) with firmware-defined values:
  - `T` from `pdMS_TO_TICKS` in `src/my_tasks_input.cpp:205` (10), `my_tasks_audio.cpp:40` (25), `my_tasks_ui.cpp:145` (33), `my_tasks_matrix.cpp:39` (50), `my_tasks_sensor.cpp:42` (200), `include/my/config.hpp:88` (CharLCD 500), `include/my/config.hpp:96` (Vogon 400).
  - `Prio/Core/Stack` from `include/my/config/priorities.hpp:18` (Audio 3/core0/16384, Input 2/core0/16384, rest 1).
  - `C` not `#define`d in firmware — labelled `C_est` from `lib/profiling` `PROFILE_BLOCK` worst-path estimate, to be replaced by measured max from `bonus/flamegraph/flamegraph.py`.
- Switched to per-core analysis: Core0 `Input>Audio>Sensor` (`U=0.575<0.780`, RTA `13≤25`, `16≤200`), Core1 `UI>Matrix>Vogon>CharLCD` (`U=0.251<0.757`, RTA `8≤50`, `21≤500`).
- I2C blocking now `SDA2/SCL1` single resource with CS 2–4 ms + `delays.hpp:43` `I2C_TRANSACTION_TIMEOUT_MS=50`, `PIP 6→PCP 4`, not exam `R1–R5` matrix (`blocking_times.py:18`).
- New Gantts `gantt_core0_rm.png`, `gantt_core1_rm.png`, `gantt_core0_edf.png`.

## 2026-09-16 — Initial deck (exam-based, 7 slides)
- Created `bonus/rta/lenv/` (python-pptx, matplotlib, pillow) and `generate_presentation.py` (7 slides, 16:9) from `bonus/rta/*.py` calculators:
  - Task set `b/c/d/a` (Q3), EDF `τ1–τ4` (Q5/Q6), `R1–R5` (Q4) with Gantts `gantt_rm/edf(_np).png`.
  - Exported `Bloated_MP3_Player_RT_Deadline_Presentation.pptx` + `pdf` via LibreOffice.

## Rebuild
```bash
bonus/rta/lenv/bin/python bonus/rta/generate_presentation.py
libreoffice --headless --convert-to pdf --outdir bonus/rta bonus/rta/Bloated_MP3_Player_RT_Deadline_Presentation.pptx
```

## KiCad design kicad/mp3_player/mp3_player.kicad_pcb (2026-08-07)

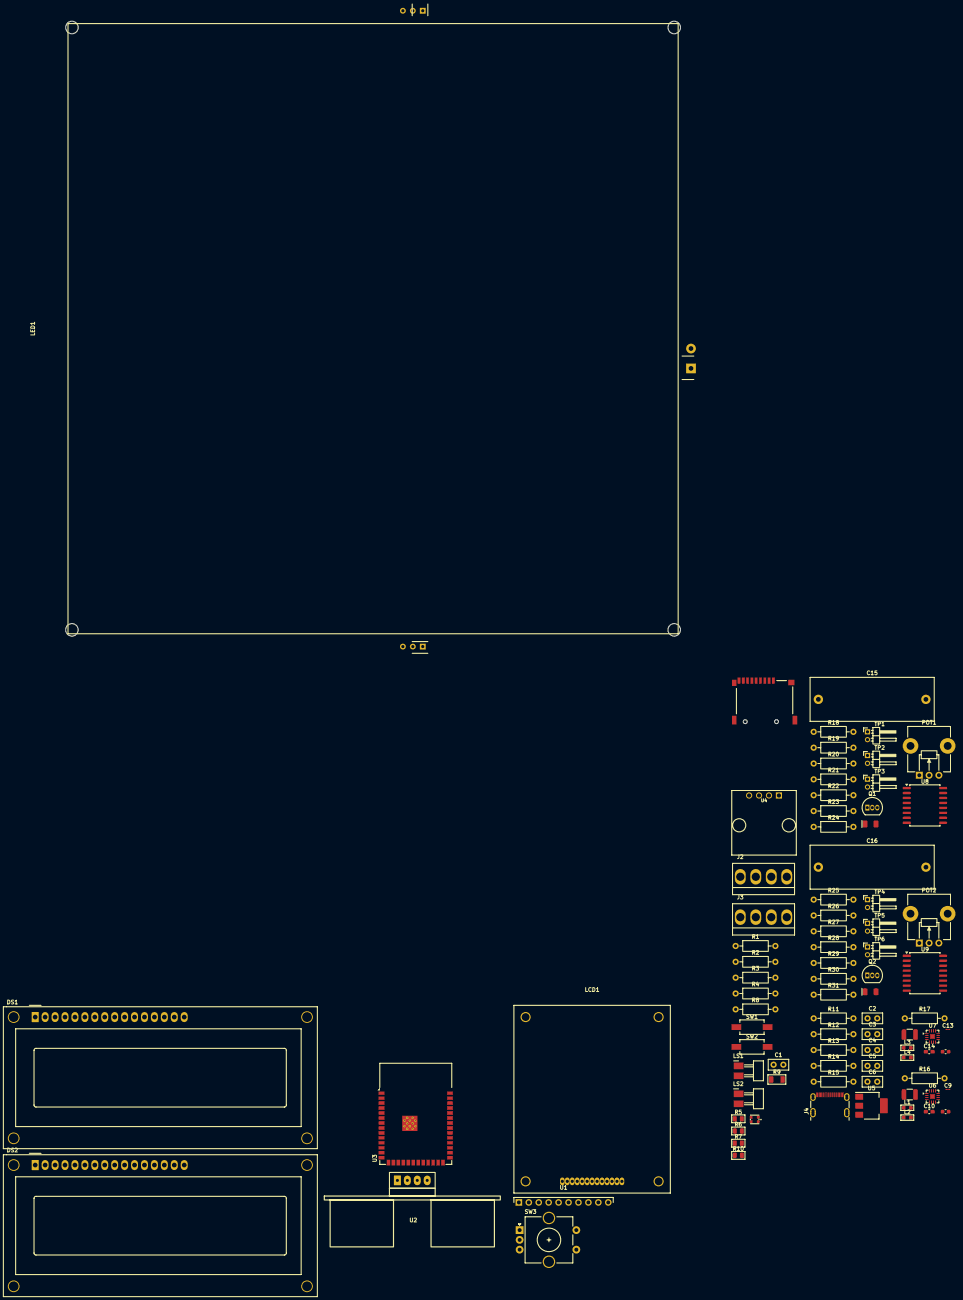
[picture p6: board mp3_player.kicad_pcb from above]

Board: 2 copper layers, 86 parts (0 on the bottom side), 80 nets, no tracks yet.

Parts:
C1: 100nF_Ceramic; C_Disc_D5.0mm_W2.5mm_P2.50mm
C2: 1nF_Ceramic; C_Disc_D5.0mm_W2.5mm_P2.50mm
C3, C5: 10uF; C_Disc_D5.0mm_W2.5mm_P2.50mm
C4, C6: 100nF; C_Disc_D5.0mm_W2.5mm_P2.50mm
C7, C11: 10uF; C_1210_3225Metric
C8, C12: 0.1uF; C_0603_1608Metric
C9, C13: 220pF_0603_25V; C_01005_0402Metric_Pad0.57x0.30mm_HandSolder
C10, C14: 220pF_0603_25V; C_0603_1608Metric_Pad1.08x0.95mm_HandSolder
C15, C16: 0.1uF; C_Rect_L31.5mm_W11.0mm_P27.50mm_MKS4
D1: WS2812B; WS2812_2020
D2, D3: Blue; LED_1206_3216Metric_Blue
DS1: WC2004A; WC1602A
DS2: WC1602A
J1: microSD; microSD_External_Pin
J2, J3: Conn_01x04; Pins_1x04_3.96mm_TH_MTA156
J4: Conn_USB_C_Socket; Conn_USB_C_Socket_Molex_2171790001
L1, L2, L3, L4: 33nH; R_0603_1608Metric_Pad0.98x0.95mm_HandSolder
LCD1: LCD-13pin; LCD_1x13_P1.27mm_Vertical
LED1: LED_Matrix_16x16_WS2812B
LS1, LS2: Speaker; PinHeader_01x02_P2.54mm_Horizontal_SMD
POT1, POT2: 16mm_CtrDet_10k; Potentiometer_TT_P0915N
Q1, Q2: S8050; TO-92_Inline
R1: 2.2k; R_Axial_DIN0207_L6.3mm_D2.5mm_P10.16mm_Horizontal
R2, R18, R19, R20, R22, R25, R26, R27, R29: 1k; R_Axial_DIN0207_L6.3mm_D2.5mm_P10.16mm_Horizontal
R3, R4: 4.7k; R_Axial_DIN0207_L6.3mm_D2.5mm_P10.16mm_Horizontal
R5, R6, R7, R10: R_0805; R_0805_2012Metric
R8: 220ohm; R_Axial_DIN0207_L6.3mm_D2.5mm_P10.16mm_Horizontal
R9: R_1206; R_1206_3216Metric
R11, R16, R17: 1M; R_Axial_DIN0207_L6.3mm_D2.5mm_P10.16mm_Horizontal
R12, R13: 5.1k; R_Axial_DIN0207_L6.3mm_D2.5mm_P10.16mm_Horizontal
R14, R15: 10k; R_Axial_DIN0207_L6.3mm_D2.5mm_P10.16mm_Horizontal
R21, R23, R24, R28, R30, R31: 47k; R_Axial_DIN0207_L6.3mm_D2.5mm_P10.16mm_Horizontal
SW1: Boot; Button_CnK_PTS636.0_6x3.5mm
SW2: Reset; Button_CnK_PTS636.0_6x3.5mm
SW3: RotaryEncoder_Switch; RotaryEncoder_Alps_EC11E-Switch_Vertical_H20mm_CircularMoun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
TP1, TP2, TP3, TP4, TP5, TP6: TestPoint_2Pole; PinHeader_1x02_P2.00mm_Horizontal
U1: MPU6500-breakout; GY-6500_1x10_P2.54mm_Vertical
U2: HC-SR04_Ultrasonic_Sensor
U3: ESP32-S3-WROOM-1
U4: AHT20_BMP280
U5: AMS1117-3.3; SOT-223-3_TabPin2
U6, U7: MAX98357A; TQFN-16-1EP_3x3mm_P0.5mm_EP1.23x1.23mm
U8, U9: PCF8574T; SOIC-16W_7.5x10.3mm_P1.27mm

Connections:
5V: C3.1, C7.2, C8.2, C11.2, C12.2, C15.1, C16.1, D2.2 (A), D3.2 (A), DS1.2 (VDD), DS1.15 (LED(+)), DS2.2 (VDD), J2.2, J3.2, J4.A4 (VBUS), J4.A9 (VBUS), J4.B4 (VBUS), J4.B9 (VBUS), LED1.1 (5V_IN), POT1.1 (Left), POT2.1 (Left), R16.1, R16.2, R17.1, R17.2, R19.1, R20.1, R21.2, R22.1, R23.2, R24.1, R26.1, R27.1, R28.2, R29.1, R30.2, R31.1, U2.1 (VCC), U6.4 (~SD_MODE), U6.7 (VDD), U6.8 (VDD), U7.4 (~SD_MODE), U7.7 (VDD), U7.8 (VDD), U8.16 (VDD), U9.16 (VDD)
/ESP power/EN: R14.2, SW2.2
/ESP power/ESP32_USB_D+: J4.A6 (Dp1), J4.B7 (Dn2), U3.14 (USB_D+)
/ESP power/ESP32_USB_D-: J4.A7 (Dn1), J4.B6 (Dp2), U3.13 (USB_D-)
/ESP power/IO0: R15.2, SW1.2
/I2C1/(K) BL-: DS1.16 (LED(-)), Q2.3 (C)
/I2C1/A0: R26.2, TP4.1, U9.1 (A0)
/I2C1/A1: R27.2, TP5.1, U9.2 (A1)
/I2C1/A2: R29.2, TP6.1, U9.3 (A2)
/I2C1/DB4: DS1.11 (D4), U9.9 (P4)
/I2C1/DB5: DS1.12 (D5), U9.10 (P5)
/I2C1/DB6: DS1.13 (D6), U9.11 (P6)
/I2C1/DB7: DS1.14 (D7), U9.12 (P7)
/I2C1/E: DS1.6 (E), U9.6 (P2)
/I2C1/RS: DS1.4 (RS), U9.4 (P0)
/I2C1/R/W: DS1.5 (R/W), U9.5 (P1)
/I2C1/V0: DS1.3 (VO), POT2.2 (Center)
/I2C/(K) BL-: DS2.16 (LED(-)), Q1.3 (C)
/I2C/A0: R19.2, TP1.1, U8.1 (A0)
/I2C/A1: R20.2, TP2.1, U8.2 (A1)
/I2C/A2: R22.2, TP3.1, U8.3 (A2)
/I2C/DB4: DS2.11 (D4), U8.9 (P4)
/I2C/DB5: DS2.12 (D5), U8.10 (P5)
/I2C/DB6: DS2.13 (D6), U8.11 (P6)
/I2C/DB7: DS2.14 (D7), U8.12 (P7)
/I2C/E: DS2.6 (E), U8.6 (P2)
/I2C/RS: DS2.4 (RS), U8.4 (P0)
/I2C/R/W: DS2.5 (R/W), U8.5 (P1)
/I2C/SCL: J2.4, J3.4, R3.1, R23.1, R30.1, U1.3 (SCL), U1.6 (ECL), U3.39 (IO1), U4.SCL, U8.14 (SCL), U9.14 (SCL)
/I2C/SDA: J2.3, J3.3, R4.1, R21.1, R28.1, U1.4 (SDA), U1.5 (EDA), U3.38 (IO2), U4.SDA, U8.15 (SDA), U9.15 (SDA)
/I2C/V0: DS2.3 (VO), POT1.2 (Center)
/MAX98357/BCLK: U3.9 (IO16), U6.16 (BCLK), U7.16 (BCLK)
/MAX98357/DIN: U3.11 (IO18), U7.1 (DIN)
/MAX98357/LRCLK: U3.24 (IO47), U6.14 (LRCLK), U7.14 (LRCLK)
/MAX98357/VD+: C13.1, L3.2, LS2.1
/MAX98357/VD-: C14.1, L4.2, LS2.2
/MAX98358/DIN: U3.10 (IO17), U6.1 (DIN)
/MAX98358/VD+: C9.1, L1.2, LS1.1
/MAX98358/VD-: C10.1, L2.2, LS1.2
GND: C2.1, C4.1, C7.1, C8.1, C9.2, C10.2, C11.1, C12.1, C13.2, C14.2, C15.2, C16.2, D1.2 (VSS), DS1.1 (VSS), DS2.1 (VSS), J1.6 (VSS), J1.10 (SHIELD), J2.1, J3.1, J4.A1 (GND), J4.A12 (GND), J4.B1 (GND), J4.B12 (GND), LCD1.7 (VSS), LCD1.9 (K), LED1.3 (GND_IN), LED1.6 (GND_OUT), LED1.8 (GND), POT1.3 (Right), POT2.3 (Right), Q1.1 (E), Q2.1 (E), R1.1, R11.1, R12.2, R13.2, R18.1, R25.1, SW3.C, SW3.S1, TP1.2, TP2.2, TP3.2, TP4.2, TP5.2, TP6.2, U1.2 (GND), U1.7 (AD0), U1.10 (FSYNC), U2.4 (GND), U3.1 (GND), U3.40 (GND), U3.41 (GND), U4.GND, U5.2 (GND), U6.3 (GND), U6.11 (GND), U6.15 (GND), U6.17 (PAD), U7.3 (GND), U7.11 (GND), U7.15 (GND), U7.17 (PAD), U8.8 (GND), U9.8 (GND)
unnamed: C4.2, C5.1
unnamed: D1.3 (DIN), U3.25 (IO48)
unnamed: D2.1 (K), R18.2
unnamed: D3.1 (K), R25.2
unnamed: J1.5 (CLK/SCK), R6.2
unnamed: C1.1, J1.3 (CMD/SDI), R7.2, R9.2
unnamed: J1.7 (DAT0/SDO), R5.2, R10.2
unnamed: J4.A5 (CC1), R12.1
unnamed: J4.B5 (CC2), R13.1
unnamed: C2.2, J4.S1 (SHIELD), R11.2
unnamed: LCD1.8 (A), R8.2
unnamed: LCD1.1 (CS), U3.18 (IO10)
unnamed: LCD1.11 (IC_CS), U3.5 (IO5)
unnamed: LCD1.12 (IC_S0), U3.4 (IO4)
unnamed: LCD1.5 (SI), LCD1.13 (IC_S1), U3.6 (IO6)
unnamed: LCD1.4 (SCL), LCD1.10 (IC_SCL), U3.7 (IO7)
unnamed: LCD1.3 (RS), U3.12 (IO8)
unnamed: LCD1.2 (RSE), U3.17 (IO9)
unnamed: LED1.2 (DIN), U3.34 (IO41)
unnamed: Q1.2 (B), R24.2, U8.7 (P3)
unnamed: Q2.2 (B), R31.2, U9.7 (P3)
unnamed: U1.8 (INT), U3.19 (IO11)
unnamed: R2.1, U2.3 (ECHO)
unnamed: U2.2 (TRIG), U3.22 (IO14)
unnamed: SW2.1, U3.3 (EN)
unnamed: SW1.1, U3.27 (IO0)
unnamed: SW3.S2, U3.20 (IO12)
unnamed: R1.2, R2.2, U3.21 (IO13)
unnamed: SW3.B, U3.8 (IO15)
unnamed: R7.1, U3.31 (IO38)
unnamed: R6.1, U3.32 (IO39)
unnamed: R5.1, U3.33 (IO40)
unnamed: SW3.A, U3.35 (IO42)
unnamed: C3.2, U5.1 (IN)
unnamed: C6.1, U5.3 (OUT)
unnamed: L2.1, U6.10 (OUTN)
unnamed: L1.1, U6.9 (OUTP)
unnamed: L4.1, U7.10 (OUTN)
unnamed: L3.1, U7.9 (OUTP)
PWR_3V3: C1.2, C5.2, C6.2, D1.4 (VDD), J1.4 (VDD), LCD1.6 (VDD), R3.2, R4.2, R8.1, R9.1, R10.1, R14.1, R15.1, U1.1 (VCC), U1.9 (NCS), U3.2 (3V3), U4.VDD

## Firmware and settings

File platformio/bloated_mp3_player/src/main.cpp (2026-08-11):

/*
* +==== BEGIN Bloated MP3 Player =================+
* LOGO:
* ......................
* ..________________...
* ..|.>_............|..
* ..|..DON'T........|..
* ..|..PANIC!.......|..
* ..|_______________|..
* ......................
* /STOP
* PROJECT: Bloated MP3 Player
* FILE: main.cpp
* CREATION DATE: 15-07-2026
* LAST Modified: 19:35:28 31-07-2026
* DESCRIPTION:
* The main event loop. Spawns FreeRTOS tasks for every subsystem that
* doesn't absolutely need to run on the same core, and a few that do.
* Like a Vogon ship, everything runs on sheer improbability and
* inadequate power budgets.
* /STOP
* COPYRIGHT: (c) Henry Letellier
* PURPOSE: Multithreaded chaos coordinator for the bloated MP3 player.
* // AR
* +==== END Bloated MP3 Player =================+
*/
// System required libraries
#include <Arduino.h>
#include <Adafruit_NeoPixel.h>

// I2C handling
#include <Wire.h>

// onboard libraries (compiled alongside the program)
#include <leds.hpp>
#include <matrix.hpp>
#include <ultrasonic.hpp>
#include <rotary.hpp>
#include <audio.hpp>
#include <environmental.hpp>
#include <imu.hpp>
#include <bluetooth.hpp>
#include <sdcard.hpp>
#include <profiling.hpp>
#include <fonts.hpp>
#include <images.hpp>
#include <uicommon.hpp>

#include <uimatrix.hpp>
#include <filexplorer.hpp>
#include <turtle.hpp>

// program level includes
#include "my.hpp"
#include "shared_instances.hpp"

static void profiling_output(const char *msg)
{
    SharedInstances::serial.serial_print_raw(msg);
}

void boot_screen()
{
    // Screen
    SharedInstances::lcd.begin(My::Config::DISPLAY_CONTRAST);
    SharedInstances::lcd.clear();
    // Demo: draw a play icon from the generated assets
    SharedInstances::lcd.drawAscii(
        baseline_play_circle_filled_black_48dp_bits,
        baseline_play_circle_filled_black_48dp_WIDTH,
        baseline_play_circle_filled_black_48dp_HEIGHT,
        1,
        1
    );
    SharedInstances::lcd.display();
    delay(500);
    SharedInstances::lcd.clear();
    SharedInstances::lcd.setFont(My::Config::FONT_BOOT);
    SharedInstances::lcd.printAt("Booting...", My::Config::DisplayLayout::BOOTING_X, My::Config::DisplayLayout::BOOTING_Y);
    SharedInstances::lcd.display();
}

bool discover_audio_tracks()
{
    if (!SDCard::is_mounted()) {
        SharedInstances::serial.serial_print(My::Infos::UART::warn_sd_not_mounted);
        return false;
    }
    SharedInstances::lcd.clear();
    SharedInstances::lcd.setFont(My::Config::FONT_BOOT);
    SharedInstances::lcd.printAt("Booting...", My::Config::DisplayLayout::BOOTING_X, My::Config::DisplayLayout::BOOTING_Y);
    SharedInstances::lcd.printAt("Discovering music...", My::Config::DisplayLayout::AUDIO_DISCOVERING_X, My::Config::DisplayLayout::AUDIO_DISCOVERING_Y);
    SharedInstances::lcd.display();
    SharedInstances::serial.serial_print(My::Infos::UART::sd_scanning);
    bool ok = SDCard::scan_tracks("/");
    SharedInstances::serial.serial_print(My::Infos::UART::sd_found, SDCard::total_tracks());
    return ok;
}

// ─── Setup ────────────────────────────────────────────────────────────
void setup()
{
    // Initialise serial
    SharedInstances::serial.initialise();
    SharedInstances::my_threads.initialise_serial();
    delay(My::Config::Delays::SERIAL_INITIALISATION_DELAY);

    // From now on all output goes through the serial queue, so there is
    // no contention: each task sends its message in one atomic
    // xQueueSend call, and the single serial_output_task drains in
    // order.  It also means tasks never block waiting for UART DMA.

    // Route profiler output through the queue-based serial
    if (My::Config::Debug::UART_PROFILING_ENABLED) {
        Profiler::set_output(profiling_output);
    }
    Profiler::set_enabled(My::Config::Debug::UART_PROFILING_ENABLED);

    // Display boot message
    SharedInstances::serial.serial_print(My::Infos::UART::boot_title);
    SharedInstances::serial.serial_print(My::Infos::UART::quote_ships_bricks);

    // Onboard LED – init first, then colour
    SharedInstances::onboard.init();
    SharedInstances::onboard.set_colour(My::LED::blue_colour, 0, -1, My::LED::black_colour);
    SharedInstances::onboard.refresh();

    // LCD Screen
    SharedInstances::lcd.initialise();
    boot_screen();

    // LED matrix
    Matrix::begin(
        (My::Config::MATRIX_LED_COUNT_HORIZONTAL * My::Config::MATRIX_LED_COUNT_VERTICAL),
        My::Config::MATRIX_LED_COUNT_HORIZONTAL,
        My::Config::Pins::MATRIX_PIN
    );

    // Quick hardware test: light all LEDs white briefly (gated off by
    // default — the 256-LED spike pulls the 5V rail hard during boot and,
    // with the matrix task disabled, the fill never gets overwritten).
    if (My::Config::Debug::MATRIX_BOOT_FILL) {
        for (uint16_t i = 0; i < (My::Config::MATRIX_LED_COUNT_HORIZONTAL * My::Config::MATRIX_LED_COUNT_VERTICAL); i++) {
            Matrix::set_pixel(i, My::LED::white_colour);
        }
        Matrix::show();
        delay(2100);
    }

    Matrix::set_animation(Matrix::Animation::Rainbow);

    // I2C sensors 
    Wire.begin(My::Config::Pins::I2C_SDA_PIN, My::Config::Pins::I2C_SCL_PIN);
    Wire.setTimeout(My::Config::Delays::I2C_TRANSACTION_TIMEOUT_MS);

    // Shared I2C bus mutex: the two PCF8574 LCD backpacks, the AHT20/BMP280
    // and the MPU6050 share one Wire bus driven from different FreeRTOS
    // tasks. Without this lock, interleaved beginTransmission/endTransmission
    // sequences corrupt each other (garbled characters, stuck I2C).
    SharedInstances::i2c_bus_lock = xSemaphoreCreateMutex();
    if (SharedInstances::i2c_bus_lock != nullptr) {
        SharedInstances::char_lcd.set_bus_lock(SharedInstances::i2c_bus_lock);
        SharedInstances::char_lcd_vogon.set_bus_lock(SharedInstances::i2c_bus_lock);
    }

    // Character LCD (PCF8574 backpack on the same I2C bus) -- boot notice
    SharedInstances::char_lcd.begin();
    SharedInstances::char_lcd.backlight(true);
    SharedInstances::char_lcd.print_at(0, 0, My::Infos::LCD::boot_name);
    SharedInstances::char_lcd.print_at(0, 1, My::Infos::LCD::boot_motto);
    SharedInstances::char_lcd.print_at(0, 2, "%-20.20s", My::Infos::LCD::booting_i2c);

    // Second 1602A: the Vogon panel, brought online with its own motto.
    SharedInstances::char_lcd_vogon.begin();
    SharedInstances::char_lcd_vogon.backlight(true);

    // Environmental (AHT20+BMP280)
    if (!SharedInstances::environmental.begin()) {
        SharedInstances::serial.serial_print(My::Infos::UART::warn_environmental);
        SharedInstances::char_lcd.print_at(0, 2, "%-20.20s", My::Infos::LCD::i2c_fail);
        delay(My::Config::Delays::ENVIRONMENTAL_INITIALISATION_ISSUE_MS);
    } else {
        SharedInstances::char_lcd.print_at(0, 2, "%-20.20s", My::Infos::LCD::i2c_ok);
    }

    // IMU
    if (!IMU::begin(My::Config::Pins::I2C_SDA_PIN, My::Config::Pins::I2C_SCL_PIN)) {
        SharedInstances::serial.serial_print(My::Infos::UART::warn_imu);
        delay(My::Config::Delays::IMU_INITIALISATION_FAILURE_MS);
    }
    SharedInstances::char_lcd.print_at(0, 2, "%-20.20s", My::Infos::LCD::booting_sd);

    // SD card (SDMMC 1-bit mode on hardware pins 38/39/40)
    if (!SDCard::begin(My::Config::Pins::SDMMC_CLK, My::Config::Pins::SDMMC_CMD, My::Config::Pins::SDMMC_D0)) {
        SharedInstances::serial.serial_print(My::Infos::UART::warn_sd_card);
        SharedInstances::char_lcd.print_at(0, 2, "%-20.20s", My::Infos::LCD::sd_missing);
        delay(My::Config::Delays::SD_CARD_NOT_PRESENT_MESSAGE_MS);
    } else {
        if (!discover_audio_tracks()) {
            SharedInstances::serial.serial_print(My::Infos::UART::warn_no_music);
            SharedInstances::char_lcd.print_at(0, 2, "%-20.20s", My::Infos::LCD::sd_no_music);
            delay(My::Config::Delays::SD_CARD_NO_MUSIC_PRESENT_MS);
        } else {
            SharedInstances::char_lcd.print_at(0, 2, My::Infos::LCD::sd_tracks, (unsigned long)SDCard::total_tracks());
        }
    }
    SharedInstances::char_lcd.print_at(0, 3, "%-20.20s", My::Infos::LCD::booting_audio);

    // Audio
    if (!SharedInstances::audio.open()) {
        SharedInstances::serial.serial_print(My::Infos::UART::warn_i2s, (unsigned long)SharedInstances::audio.last_error());
        SharedInstances::char_lcd.print_at(0, 3, "%-20.20s", My::Infos::LCD::audio_fail);
        delay(My::Config::Delays::AUDIO_HANDLER_I2S_OPEN_FAILURE_MS);
    } else {
        SharedInstances::char_lcd.print_at(0, 3, "%-20.20s", My::Infos::LCD::audio_ok);
    }
    SharedInstances::audio.setVolume(My::Config::AUDIO_VOLUME_DEFAULT);

    // Input devices
    Rotary::begin(My::Config::Pins::ROTARY_PIN_A, My::Config::Pins::ROTARY_PIN_B, My::Config::Pins::ROTARY_SW_PIN);
    Rotary::set_quadrature_decode(My::Config::Debug::ROTARY_QUADRATURE_DECODE);
    Rotary::set_direction_inverted(My::Config::Debug::ROTARY_DIRECTION_INVERTED);
    Ultrasonic::begin(My::Config::Pins::ULTRA_TRIG_PIN, My::Config::Pins::ULTRA_ECHO_PIN);

    // Bluetooth (BLE UART bridge — classic SPP isn't in the S3 SDK)
    if (!SharedInstances::bluetooth.begin(My::Config::BT_DEVICE_NAME)) {
        SharedInstances::serial.serial_debug(
            My::Config::Debug::UART_BT_BRIDGE,
            My::Infos::UART::bt_bridge_fail
        );
    } else {
        SharedInstances::serial.serial_debug(
            My::Config::Debug::UART_BT_BRIDGE,
            My::Infos::UART::bt_bridge_ready
        );
    }

    // Artificial delay (to read the initialisaiton issues)
    delay(My::Config::Delays::PRE_THREAD_INITIALISATION_DELAY);

    // ─── Spawn FreeRTOS tasks ─────────────────────────────────────────
    SharedInstances::my_threads.initialise_ui();
    SharedInstances::my_threads.initialise_audio();
    SharedInstances::my_threads.initialise_sensors();
    SharedInstances::my_threads.initialise_led();
    // SharedInstances::my_threads.initialise_matrix();
    SharedInstances::my_threads.initialise_input();
    SharedInstances::my_threads.initialise_vogon_panel();
    SharedInstances::my_threads.initialise_char_lcd();

    SharedInstances::serial.serial_print(My::Infos::UART::all_tasks_spawned);
    if (My::Config::Debug::UART_PROFILING_ENABLED) {
        Profiler::dump_task_stats();
    }
}

void loop()
{
    // Kill the arduino loop.
    vTaskDelete(NULL);
}

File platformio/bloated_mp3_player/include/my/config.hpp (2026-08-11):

/*
* +==== BEGIN Bloated MP3 Player =================+
* LOGO:
* .......................
* ...><>.............<><.
* ..><>.><>.......<><.<><
* .><>.<><.><>.<><.<><.<>
* ..><>.><>.......<><.<><
* ...><>.............<><.
* .......................
* /STOP
* PROJECT: Bloated MP3 Player
* FILE: config.hpp
* CREATION DATE: 17-07-2026
* LAST Modified: 13:22:18 07-08-2026
* DESCRIPTION:
* This is the code in charge of making the bloated player come to life.
* /STOP
* COPYRIGHT: (c) Henry Letellier
* PURPOSE: This file contains the configuration used in the program for stability and usage.
* // AR
* +==== END Bloated MP3 Player =================+
*/

#pragma once
#include <stdint.h>
#include <U8g2lib.h>
#include <fonts.hpp>
#include "config/pins.hpp"
#include "config/debug.hpp"
#include "config/delays.hpp"
#include "config/priorities.hpp"
#include "config/onboard_led.hpp"
#include "config/display_layout.hpp"


namespace My
{
    namespace Config
    {
        // ─── Serial Baudrate ─────────────────────────────────────────────────────
        static const unsigned long UART_BAUD = 115200;

        // ─── Serial Buffer ───────────────────────────────────────────────────────
#ifndef SERIAL_MSG_LEN
#define SERIAL_MSG_LEN 128
#endif

#ifndef SERIAL_QUEUE_LEN
#define SERIAL_QUEUE_LEN 16
#endif

        // ─── Display fonts ───────────────────────────────────────────────────────
        static const uint8_t *const FONT_BOOT = u8g2_font_ncenB08_tr;
        static const BakedFonts::FontHandle *const FONT_TITLE = &BakedFonts::tiny5_10pt_handle;
        static const BakedFonts::FontHandle *const FONT_BODY = &BakedFonts::tiny5_8pt_handle;
        static const BakedFonts::FontHandle *const FONT_INFO = &BakedFonts::tiny5_8pt_handle;
        // ST7565R contrast is only 6 bits (0..63): U8g2 clamps with
        // value >> 2, so 255 would become 63 = maximum bias voltage and the
        // screen goes uniformly dark with dots everywhere (data still drawn
        // underneath, visible only at an angle). 40-ish is the sweet spot
        // for GMG12864-06D. Range to explore: 30..55.
        static const uint8_t DISPLAY_CONTRAST = 40;
        static const uint32_t DISPLAY_SPI_CLOCK_HZ = 1000000;

        // ─── Matrix Setup ───────────────────────────────────────────────────────
        static const uint16_t MATRIX_LED_COUNT_HORIZONTAL = 16;
        static const uint16_t MATRIX_LED_COUNT_VERTICAL = 16;

        // ─── Audio ─────────────────────────────────────────────────────────────
        static const uint8_t AUDIO_VOLUME_STEP = 4;
        static const uint8_t AUDIO_VOLUME_MAX = 255;
        static const uint8_t AUDIO_VOLUME_MIN = 0;
        static const uint8_t AUDIO_VOLUME_DEFAULT = 100;

        // ─── Bluetooth (BLE UART bridge) ─────────────────────────────────
        // Name the device advertises as. Any phone/PC "BLE serial terminal"
        // app will list it under this name.
        static const char BT_DEVICE_NAME[] = "BloatedMP3";

        // ─── Character LCD (PCF8574 backpack, HD44780) ─────────────────────────
        // Info panel: 2004A (4 rows x 20 cols). Bridged A0 from the factory
        // state 0x27 down to 0x26 (ties the A0 pad low) so the two panels
        // can share the bus at different addresses.
        static const uint8_t CHAR_LCD_I2C_ADDR = 0x26;
        static const uint8_t CHAR_LCD_COLS = 20;
        static const uint8_t CHAR_LCD_ROWS = 4;
        static const uint32_t CHAR_LCD_REFRESH_MS = 500;

        // Fun panel: 1602A (2 rows x 16 cols) at the shipped 0x27 default
        // (all address pads open). If the two panels come up swapped on
        // the bench, the A0 bridge is on the wrong backpack — move it.
        static const uint8_t CHAR_LCD2_I2C_ADDR = 0x27;
        static const uint8_t CHAR_LCD2_COLS = 16;
        static const uint8_t CHAR_LCD2_ROWS = 2;
        static const uint32_t CHAR_LCD2_REFRESH_MS = 400;

    } // namespace Config
} // namespace My

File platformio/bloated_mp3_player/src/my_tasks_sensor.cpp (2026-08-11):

/*
* +==== BEGIN Bloated MP3 Player =================+
* LOGO:
* .......................
* ...><>.............<><.
* ..><>.><>.......<><.<><
* .><>.<><.><>.<><.<><.<>
* ..><>.><>.......<><.<><
* ...><>.............<><.
* .......................
* /STOP
* PROJECT: Bloated MP3 Player
* FILE: my_tasks_sensor.cpp
* CREATION DATE: 17-07-2026
* LAST Modified: 12:41:41 23-07-2026
* DESCRIPTION:
* This is the code in charge of making the bloated player come to life.
* /STOP
* COPYRIGHT: (c) Henry Letellier
* PURPOSE: This is the file that will define the tasks referenced in the headerfile for the sensor section.
* // AR
* +==== END Bloated MP3 Player =================+
*/

#include <imu.hpp>
#include <audio.hpp>
#include <profiling.hpp>
#include "my/tasks.hpp"
#include "my/infos.hpp"
#include "shared_instances.hpp"


namespace My
{
    namespace Tasks
    {
        // ─── Sensor Task ──────────────────────────────────────────────────────
        void sensor(void *pvParameters)
        {
            (void)pvParameters;
            TickType_t xLastWake = xTaskGetTickCount();
            const TickType_t freq = pdMS_TO_TICKS(200);
            uint8_t orientation_log_countdown = 0;
            IMU::Vec3 accel;
            IMU::Gesture g;
            SharedInstances::serial.serial_print(My::Infos::UART::sensor_time_illusion);

            while (true) {
                PROFILE_BLOCK("sensor_tick");

                if (SharedInstances::i2c_bus_lock != nullptr) {
                    xSemaphoreTake(SharedInstances::i2c_bus_lock, portMAX_DELAY);
                }
                IMU::read_accel(accel);
                g = IMU::gesture_tick();
                if (SharedInstances::i2c_bus_lock != nullptr) {
                    xSemaphoreGive(SharedInstances::i2c_bus_lock);
                }

                // Publish the latest orientation for the Vogon panel and log
                // it to UART on a sensible cadence (once per second, the
                // task ticks every 200ms).
                SharedInstances::imu_orientation = IMU::compute_orientation(accel);
                if (orientation_log_countdown == 0) {
                    orientation_log_countdown = 5;
                    SharedInstances::serial.serial_debug(
                        My::Config::Debug::UART_ANGLE_SENSOR_ORIENTATION,
                        My::Infos::UART::sensor_orientation,
                        SharedInstances::imu_orientation.roll,
                        SharedInstances::imu_orientation.pitch,
                        SharedInstances::imu_orientation.yaw
                    );
                } else {
                    orientation_log_countdown--;
                }

                switch (g) {
                    case IMU::Gesture::Shake:
                        SharedInstances::serial.serial_debug(My::Config::Debug::UART_ANGLE_SENSOR_SHAKE, My::Infos::UART::sensor_shake);
                        // Audio::stop();
                        // Audio::play_raw(nullptr, 0);
                        break;
                    case IMU::Gesture::TiltLeft:
                        SharedInstances::serial.serial_debug(My::Config::Debug::UART_ANGLE_SENSOR_TILT_LEFT, My::Infos::UART::sensor_tilt_left);
                        // Audio::pause();
                        break;
                    case IMU::Gesture::TiltRight:
                        SharedInstances::serial.serial_debug(My::Config::Debug::UART_ANGLE_SENSOR_TILT_RIGHT, My::Infos::UART::sensor_tilt_right);
                        // Audio::resume();
                        break;
                    default:
                        break;
                }

                vTaskDelayUntil(&xLastWake, freq);
            }
        }
    } // namespace Tasks
} // namespace My

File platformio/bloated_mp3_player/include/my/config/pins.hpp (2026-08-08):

/*
* +==== BEGIN Bloated MP3 Player =================+
* LOGO:
* ......................
* ...________________...
* ..|.>_.............|..
* ..|................|..
* ..|................|..
* ..|________________|..
* ......................
* /STOP
* PROJECT: Bloated MP3 Player
* FILE: pins.hpp
* CREATION DATE: 15-07-2026
* LAST Modified: 18:7:33 08-08-2026
* DESCRIPTION:
* Central pin assignment header. If the universe ever decides to rearrange
* its wiring, you only need to change things here. The rest of the code will
* carry on as if nothing happened, much like a Vogon constructor fleet.
* /STOP
* COPYRIGHT: (c) Henry Letellier
* PURPOSE: Master pin definitions for the ESP32-S3 WROOM-1. Change these
* to match your actual wiring. Or don't. I'm a comment, not a cop.
* // AR
* +==== END Bloated MP3 Player =================+
*/
#pragma once
#include <stdint.h>
namespace My
{
    namespace Config
    {
        namespace Pins
        {
            // ─── LCD (GMG12864-06D, ST7565R, 128x64 monochrome) ────────────────────
            // These are already defined in pins_lcd.hpp; we re-export them here for
            // convenience so you only need to touch one file when rewiring the cosmos.
            // GMG12864-06D (ST7565R) 128x64 monochrome LCD
            // Wiring: LCD -> ESP32-S3
            // VDD    -> 3.3V     VSS -> GND
            // A      -> 3.3V (via 100Ω)    K  -> GND
            static const uint8_t LCD_CS = 10;
            static const uint8_t LCD_RST = 9;  //shown as RSE on the schematic
            static const uint8_t LCD_DC = 8;   //shown as RS on the schematic
            static const uint8_t LCD_SCLK = 7; //shown as SCL on the schematic
            static const uint8_t LCD_MOSI = 6; //shown as SI on the schematic

            // Font ROM on same SPI bus (optional)
            static const uint8_t IC_CS = 5;    //shown as IC_CS on the schematic
            static const uint8_t IC_SCL = 7;   //shared with LCD_SCLK
            static const uint8_t IC_SO = 4;    // MISO
            static const uint8_t IC_S1 = 6;  // shared with LCD_MOSI

            // ─── Onboard addressable LED ───────────────────────────────────────────
            // Pin 48 on the ESP32-S3 WROOM-1. The same tiny LED that will blink in
            // morse code "DON'T PANIC" when the temperature sensor glitches out.
            static const uint8_t ONBOARD_LED_PIN = 48;

            // ─── I2C bus (AHT20+BMP280 temp / humidity / pressure) ────────────────
            // The AHT20+BMP280 combo sits on a standard I2C bus. It is, for all
            // intents and purposes, a very small, very polite marmot that tells you
            // how warm it is inside your pocket.
            static const uint8_t I2C_SDA_PIN = 2;//old: 5; 
            static const uint8_t I2C_SCL_PIN = 1;//old: 15;
            // In case it gets swapped in hardware, uncomment the section bellow to test
            // static const uint8_t I2C_SDA_PIN = 1;//old: 5; 
            // static const uint8_t I2C_SCL_PIN = 2;//old: 15;

            // ─── SD Card (SDMMC 1-bit mode on Freenove hardware pins) ──────────────
            // The card sits on the ESP32‑S3 dedicated SDMMC pins:
            //   IO38 = CMD
            //   IO39 = CLK
            //   IO40 = DAT0
            // No CS pin is needed in SDMMC mode.
            static const uint8_t SDMMC_CLK = 39;
            static const uint8_t SDMMC_CMD = 38;
            static const uint8_t SDMMC_D0 = 40;

            // ─── Audio out (2x MAX98357A I2S class-D amps) ─────────────────
            // Standard I2S: the two boards share BCLK + LRCK, each gets its
            // own DIN. IO16 = BCLK, IO47 = LRCK, IO17/IO18 = DIN per speaker.
            static const uint8_t I2S_BCLK_PIN = 16;
            static const uint8_t I2S_WS_PIN = 47;
            static const uint8_t I2S_DIN_PIN = 17;
            static const uint8_t I2S_DIN2_PIN = 18;

            // ─── Rotary encoder (Alps EC11E, Prusa-style) ─────────────────────────
            // Use this to navigate the UI. Turn left to go back, turn right to go
            // forward, press to confirm. It is the least confusing thing on this board.
            static const uint8_t ROTARY_PIN_A = 42;//old: 16 (conflicted with I2S BCLK);
            static const uint8_t ROTARY_PIN_B = 15;//old: 2;
            static const uint8_t ROTARY_SW_PIN = 12;//old: 3;

            // ─── Ultrasonic sensor (HC-SR04 or compatible) ────────────────────────
            // For detecting when your hand waves in front of the device, as if to
            // say "no, really, that's enough." We will copy Apple's AirPod logic,
            // which is to say: if it works, call it magic; if it doesn't, call it
            // a feature for the next revision.
            static const uint8_t ULTRA_TRIG_PIN = 14;
            static const uint8_t ULTRA_ECHO_PIN = 13;
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

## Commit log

2026-07-15 [ADD] the ressources used in the creation of the circuitry and code of the project
    [boost_converter_3_3v_to_5v.kicad_sch, esp32s3.kicad_sch, esp_power.kicad_sch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]
2026-07-17 [ADD] an initial set of libraries to depressed to do their own job
    [esp_power.kicad_sch, mp3_player.kicad_sch]
2026-07-17 [ADD] the current version of the libraries used in the project
2026-07-17 [FIX] serial output issue
    [main.cpp]
2026-07-17 [FIX] issues where lines SCL and SDA were crossed on the schematic
    [mp3_player.kicad_sch]
2026-07-20 [UPDATE] the structure of the led library
2026-07-20 [FIX] namespace issue for the led library
    [babel_fish_demo.cpp]
2026-07-20 [ADD] a configuration for the lonely onboard led
2026-07-21 [FIX] some compilation issues
    [babel_fish_demo.cpp, delays.hpp, diagnostic.cpp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]
2026-07-21 [FIX] the weroder issue of the =led library
2026-07-21 [FIX] some of the compilation issues
    [main.cpp, my_tasks_led.cpp, shared_instances.cpp]
2026-07-21 [FIX] bugs in the code
    [main.cpp, my_lcd.cpp, my_tasks_audio.cpp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]
2026-07-22 [REMOVE] useless file generated by some KiCad modules
2026-07-22 [UPDATE] the circuit connections to match the current implementation
    [mp3_player.kicad_sch]
2026-07-22 [FIX] some of the issues regarding environemental value reading
    [delays.hpp, main.cpp, shared_instances.cpp]
2026-07-22 [FIX] issue with hPa not displaying anything else but 0
    [delays.hpp, main.cpp, my_tasks_sensor.cpp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]
2026-07-22 [FIX] the issue with the hPa reading noncense
    [main.cpp, my_lcd.cpp, my_tasks_ui.cpp]
2026-07-22 [FIX] some issues with the display when it comes to custom fonts
    [config.hpp, delays.hpp, display_layout.hpp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]
2026-07-22 [FIX] some issues with the layout
    [display_layout.hpp, my_tasks_ui.cpp]
2026-07-22 [FIX] issues with spacing and a bonus of shift issue
    [my_tasks_ui.cpp]
2026-07-23 [ADD] a debug print that can be enabled/disabled
2026-07-23 [ADD] a missing no connect in the KiCad schematic
    [mp3_player.kicad_sch]
2026-07-23 [ADD] debug prints
2026-07-23 [UPDATE] the music logic, we crash but can play some music
    [debug.hpp, my_tasks_audio.cpp]
2026-07-23 [FIX] audio reading, but extremely choppy
    [my_tasks_audio.cpp]
2026-07-31 [ADD] a helper script for parsing the serial output from the esp32s3 uart channel
2026-07-31 [ADD] delays to the warning messages so that they could be read on the uart before it gets flodded with flamegraph data.
2026-07-31 [UPDATE] the uart initialisation failure message delays to be longer
    [delays.hpp, main.cpp]
2026-07-31 [ADD] debug for the led task
2026-07-31 [FIX] a stack issue with the UART logger
    [debug.hpp, main.cpp, my_serial.cpp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]
2026-07-31 [UPDATE] the audio module to work with the Hailege 5pcs LM386 Microphone AMP Amplificateur Mini Electret Microphone Amplificateur PCB DC4V-12V amps
2026-08-02 [FIX] some logic issues
    [debug.hpp, my_tasks_audio.cpp]
2026-08-05 [UPDATE] the desing of the schematic to use the current audio module
    [esp_power.kicad_sch, max98357.kicad_sch, mp3_player.kicad_pcb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]
2026-08-06 [FIX] the tone issue
    [pins.hpp, shared_instances.cpp]
2026-08-06 [UPDATE] the program to use audio files on the board instead of a constant tone
2026-08-06 [ADD] exported schematics of the pcb
2026-08-06 [UPDATE] the settings in the debug config so that the ultrasonic was not polluting the uart channel
2026-08-06 [FIX] the autoplay issue (autoplay not starting
    [debug.hpp, main.cpp]
2026-08-06 [FIX] volume handling in the config
    [config.hpp, debug.hpp, main.cpp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]
2026-08-06 [UPDATE] the scheamtic to fix the issue with the pot not detecting volume
    [mp3_player.kicad_sch]
2026-08-06 [FIX] a set of issues regarding the project
    [config.hpp, debug.hpp, my_lcd.cpp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]
2026-08-07 [FIX] the jumping values in the sound
    [config.hpp, debug.hpp]
2026-08-07 [ADD] a double click on the pot to allow the user to skip the track
    [debug.hpp, my_tasks_input.cpp]
2026-08-07 [ADD] tripple click on the pot to skip backwards while doubleclick skips forwards
    [debug.hpp, my_tasks_input.cpp]
2026-08-07 [FIX] the schematic tracking issue in KiCad
    [max98357.kicad_sch, mp3_player.kicad_sch]
2026-08-07 [UPDATE] the logic fix for the rotary encoder to be optional due to nuances in electrical connections on pots
    [debug.hpp, main.cpp]
2026-08-07 [ADD] an option to invert the pin reading of the pot for control
    [debug.hpp, main.cpp]
2026-08-07 [ADD] lcd segment displays to the project
    [esp_power.kicad_sch, max98357.kicad_sch, mp3_player.kicad_pcb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]
2026-08-07 [ADD] untested logic for the I2C screens
2026-08-08 [UPDATE] the KiCad schematic to show the pins requiring bridging on the I2C
    [mp3_player.kicad_sch, onboard_i2c.kicad_sch]
2026-08-08 [FIX] some issues with the displays
    [debug.hpp, delays.hpp, main.cpp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]
2026-08-08 [FIX] the issue with the screens not displaying content
    [english.hpp, french.hpp, italian.hpp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]
2026-08-08 [ADD] a track selection feature
2026-08-09 [UPDATE] the schematic to include the power help to avoid a crash or lcd corruption due to brown outs
    [esp_power.kicad_sch, mp3_player.kicad_sch]
2026-08-09 [UPDATE] the readme to reflect the current state of the project
2026-08-11 [ADD] configurable device name for the bluetooth logic
2026-08-11 [UPDATE] the message structure to separate uart and ui messages while storing the sentences in different languages
2026-08-11 [FIX] some overflow issues regarding connection when interaction is with the bluetooth module
    [config.hpp]
